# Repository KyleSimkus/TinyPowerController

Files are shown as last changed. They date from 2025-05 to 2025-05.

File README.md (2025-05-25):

# TinyPowerController
ATTINY85 based tunable LiPo charger, on 1 sq inch PCB, with load switch, button and multiple UX footprint options 

	Designed: 2019 02 16
	Cleaned up: 2025 05 24

	Summary:
		1 sqaure inch power controller for low power devices.
		LiPo charger with USB micro input.
		ATTINY85 for measuring battery voltage, temperature and button timing.
		Load switch for turning off downstream device.

	Charging Current:
		Pchrg is header for adjusting charging current.
		0ohm: 500mA
		4.5kohm: 200mA
		open: 50mA
		If R1 is removed and Pchrg = 64.8kohm: 15mA
		See schematic for equations.
		
	Battery voltage measurement:
		Interally connect Vref to ADC input and VCC to ADC ref.
		Sounds strange but this 'pinless' Vcc measurement does work with ATTINY85!
		
	Coin Cell Holder:
		LIR2032 holder (straight, T/H), pins fit into H1 and H3.
		Place positive pin thru H3 so it can connect to BAT+
		
	Mounting Options:
		Multi footprints were used for USB and button.
		USB: top or bottom, straight or R/A.
		Button, top: straight or R/A.
		Button, bottom: R/A

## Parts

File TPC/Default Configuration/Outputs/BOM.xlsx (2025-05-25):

Comment | Designator | Footprint | JLC-PN | Value | MPN
JST connector | BT1 | JST-DUAL-Batt - 2mm 3_5mm | C131337 |  | B2B-PH-K-S(LF)(SN)
CAP | C1, C2 | C0603 | C1705 | 4.7uF | CL10A475KP8NNNC
CAP | C4, C5, C7 | C0603 | C1525 | 0.1uF | CL10B104KO8NNNC
Diode | D1 | SOD128 | C2908821 | 60V 3A | PMEG6030ELPX
LED | D2 | 0805 [2012] LED | C6958991 | Yellow | QTLP630C3TR
LED | D3 | 0805 [2012] LED | C6368479 | Green | QTLP630C4TR/FC17-21SYGC/S530-E2/TR8
DIODE | D4, D5 | SOD523 | C3703729 |  | VESD05A1-02V-G3-08
USB micro | P1 | USBmicro-DUAL Hirose Dual sided | C132350 |  | ZX62D-B-5PA8(30)
2x PMOS | Q1 | SOT-23-6 | C157543 |  | FDC6318P
RES | R1 | R0603 | C403057 | 20k | ERJ-3EKF2002V
RES | R2 | R0603 | C116387 | 2.2k | ERJ3EKF2201V
RES | R3, R4, R8 | R0603 | C169852 | 470 | ERJ-3GEYJ471V
RES | R5 | R0603 | C169849 | 10k | ERJ-3GEYJ103V
RES | R7, R9 | R0603 | C278634 | 1M | ERJ-3GEYJ105V
BUTTON | S1 | SW Multi TH | C2828254 |  | EVQ-P7J01P
Charger | U1 | SOT-23-5 | C173380 |  | MCP73832T-2ATI/OT
MCU | U2 | 8-SOIC-5.3mm | C152192 |  | ATTINY85V-10SU

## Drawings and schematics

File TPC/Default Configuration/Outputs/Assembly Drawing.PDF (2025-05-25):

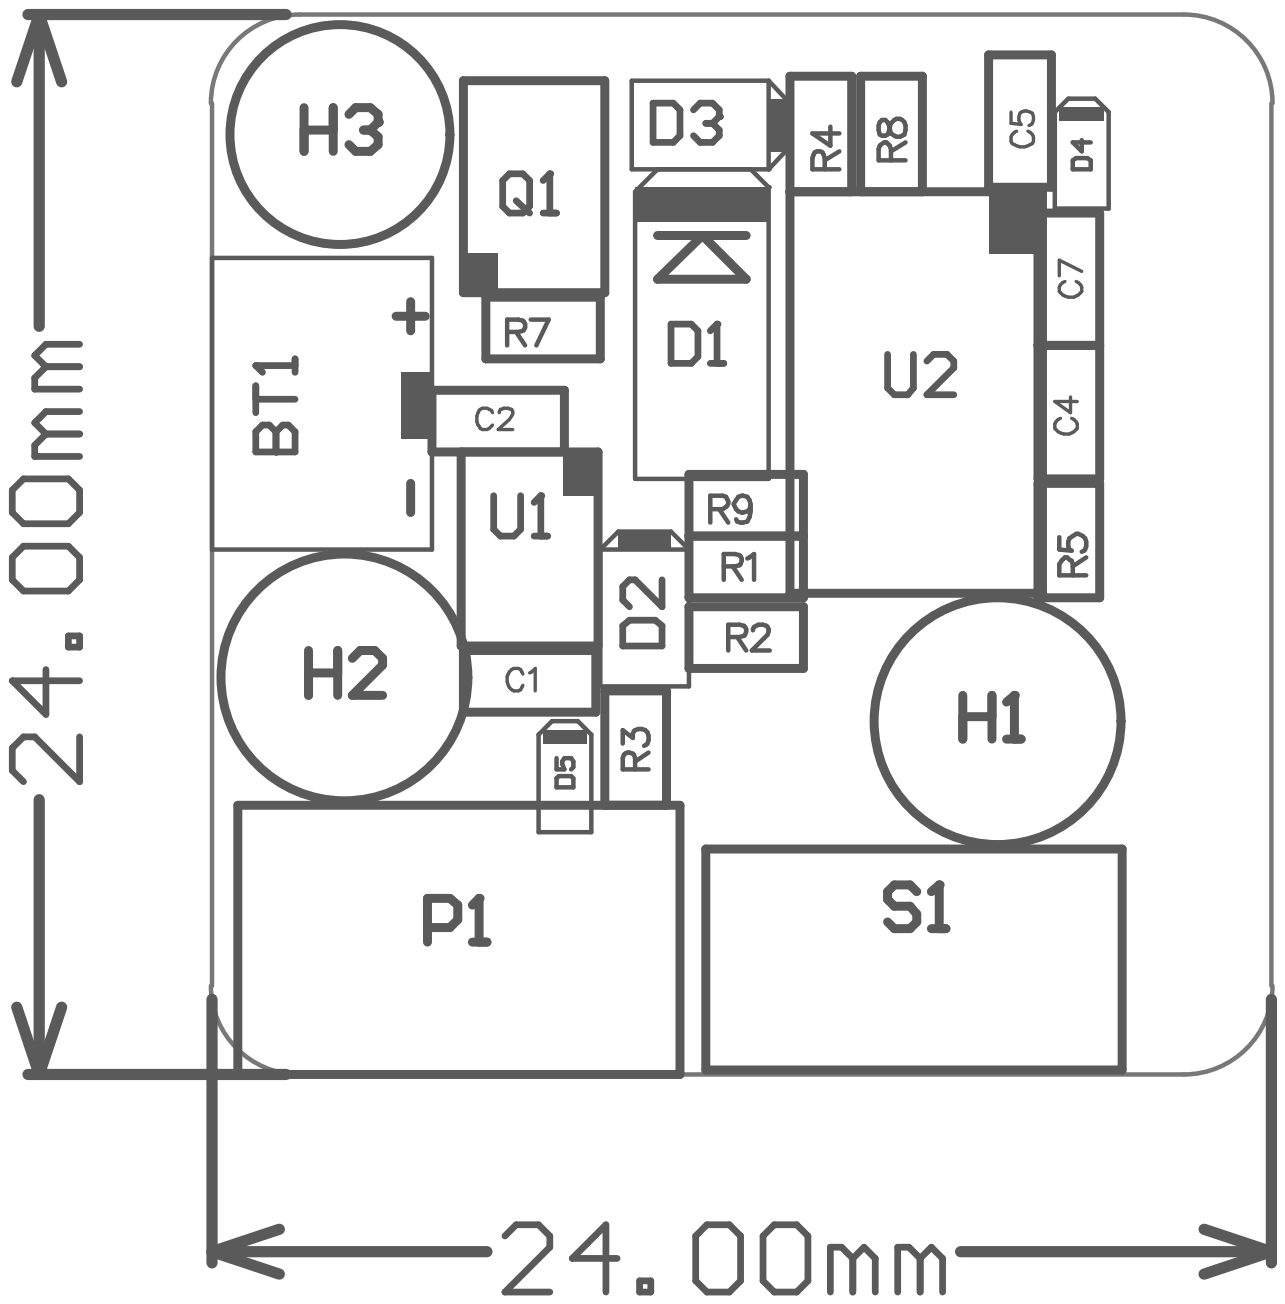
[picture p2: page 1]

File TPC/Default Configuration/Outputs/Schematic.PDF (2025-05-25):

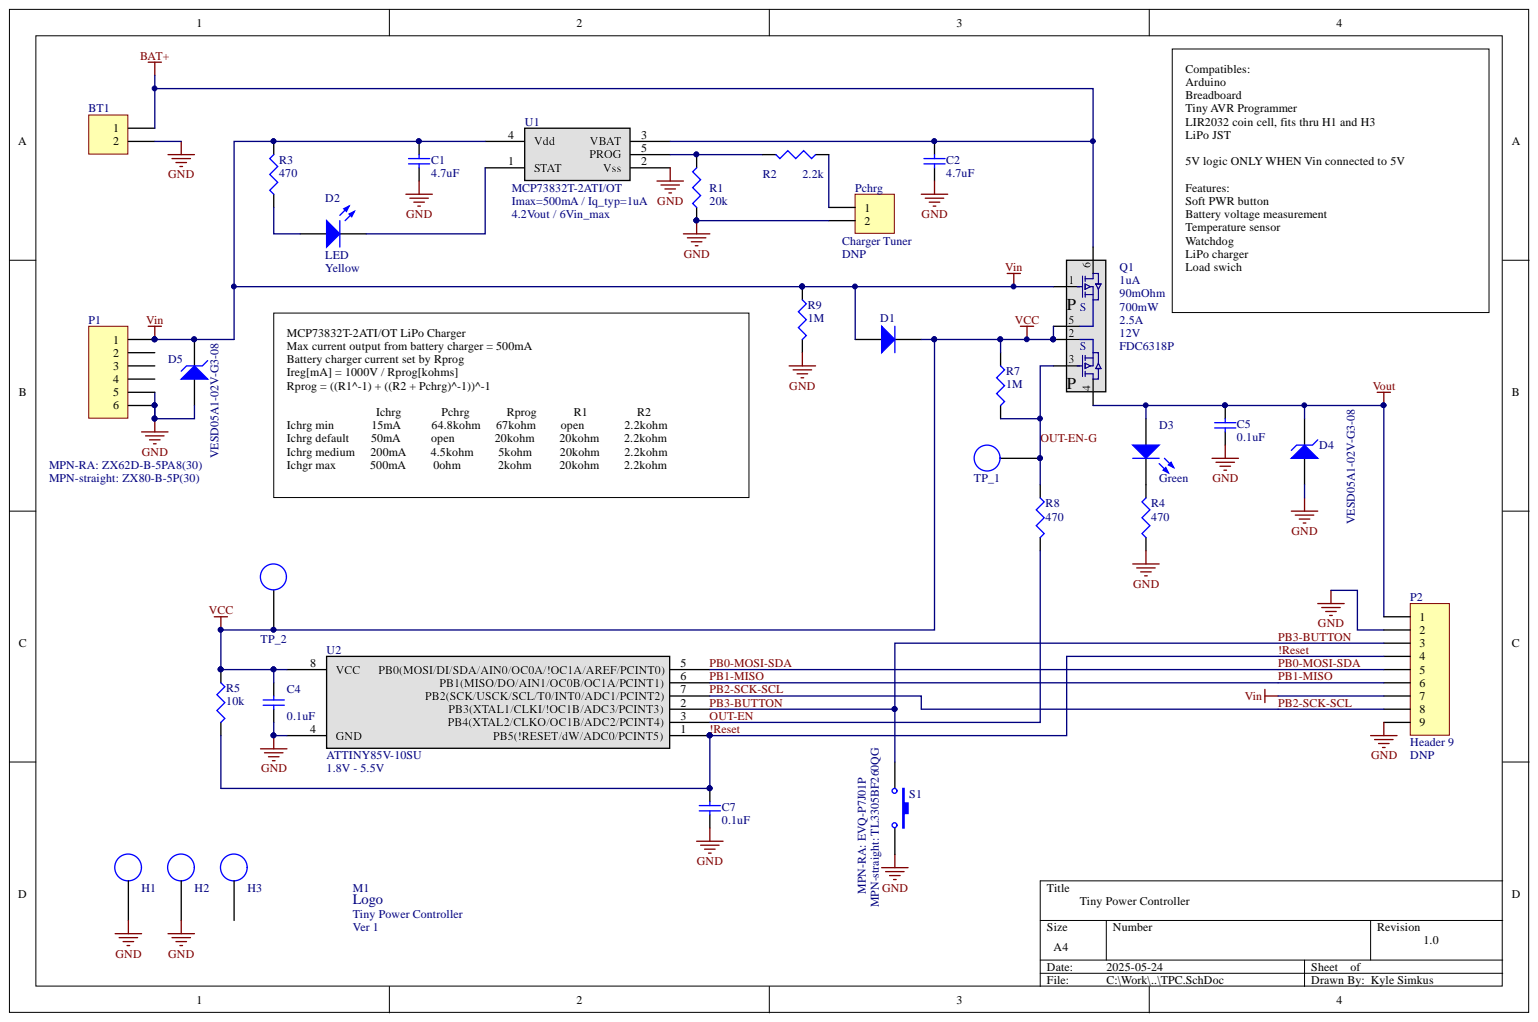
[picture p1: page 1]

L E D Yel l o w | G N D D N P

R9 | D 1 VCC | 51

MCP7 3 8 3 2 T-2 ATI/ O T L iPo Charger

Max curren t o u t p u t from bat tery charger = 5 0 0mA Bat tery charger curren t set b y Rpro g Ireg[mA] = 1 0 0 0 V / Rpro g[k o hms ] Rpro g = ((R1 ^-1) + ((R2 + Pchrg)^-1))^-1 Ichrg Pchrg Rpro g R1 R2 Ichrg mi n 1 5mA 6 4.8 k o hm 6 7 k o hm o pen 2.2 k o h m Ichrg defau l t 5 0mA o pen 2 0 k o hm 2 0 k o hm 2.2 k o h m Ichrg med i um 2 0 0mA 4.5 k o hm 5 k o hm 2 0 k o hm 2.2 k o h m Ich gr max 5 0 0mA 0 o hm 2 k o hm 2 0 k o hm 2.2 k o h m | 23 S

PB1(MISO / D O / AIN 1 / OC0B/ OC1 A /PCIN T 1 ) PB2(SCK/ USCK/SCL / T 0 /IN T 0 / A DC1 /PCIN T 2 ) PB3(X TA L 1 /CL KI/!OC1B/ A DC3 /PCIN T 3 ) PB4(X TA L 2 /CL K O / OC1B/ A DC2 /PCIN T 4 ) G N D PB5(!RESE T / d W / A DC0 /PCIN T 5 ) | 6 | PB1-MISO | PB1-MISO

7 | PB2-SCK-SCL

3 | O U T-E N
1 | !Reset
